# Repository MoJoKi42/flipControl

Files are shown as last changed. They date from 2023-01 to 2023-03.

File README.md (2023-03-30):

# flipControl
Full controller for **BROSE** and **LAWO FlipDot** panels based on STM32 µC. Controllable via RS232, RS485 or 3.3V Serial.
With the DIP switches you can decide between BROSE / LAWO and set more parameters without reprogramming.

<ins>Software/µC:</ins>
- **STM32F103C8Tx** / BluePill Dev-Board
- CubeMX and HAL Libs
- "compile_and_flash.sh" to complile and flash µC under Linux

<ins>Hardware/PCB:</ins>
- PCB + Circuit made with EAGLE 6.6.0
- Gerber Files are in "Gerber.zip"

Picture of the finished board with soldered RS323 interface:
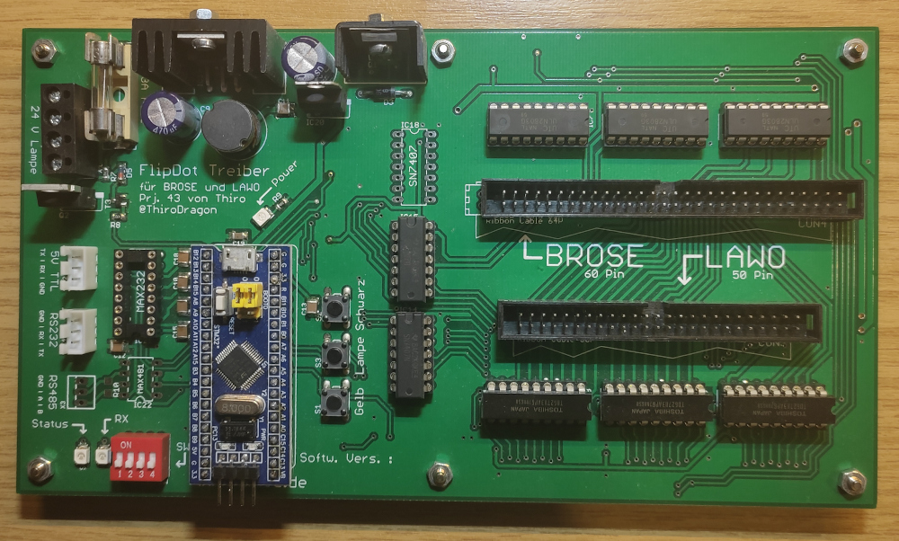
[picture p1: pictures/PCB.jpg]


Two different font types are possible (if you render the text with the MCU):
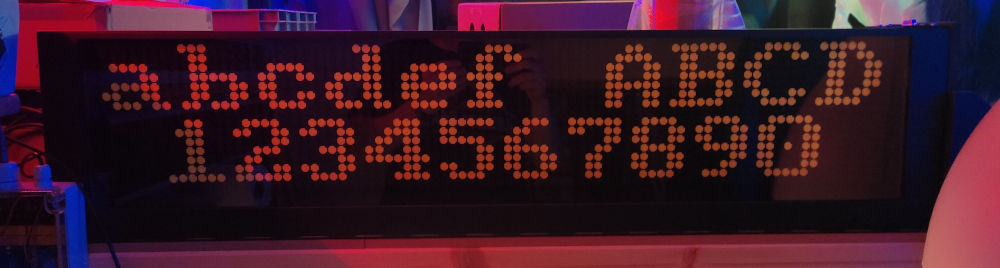
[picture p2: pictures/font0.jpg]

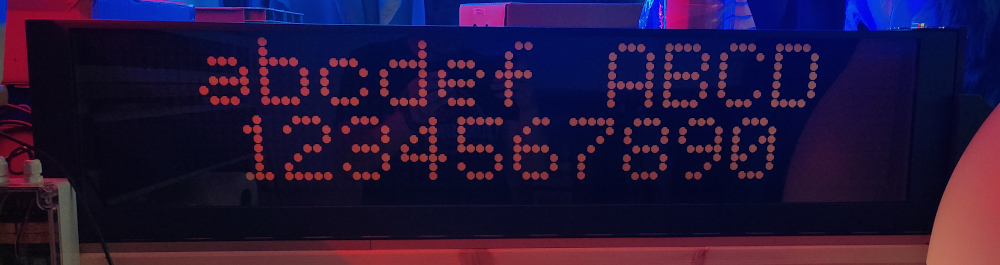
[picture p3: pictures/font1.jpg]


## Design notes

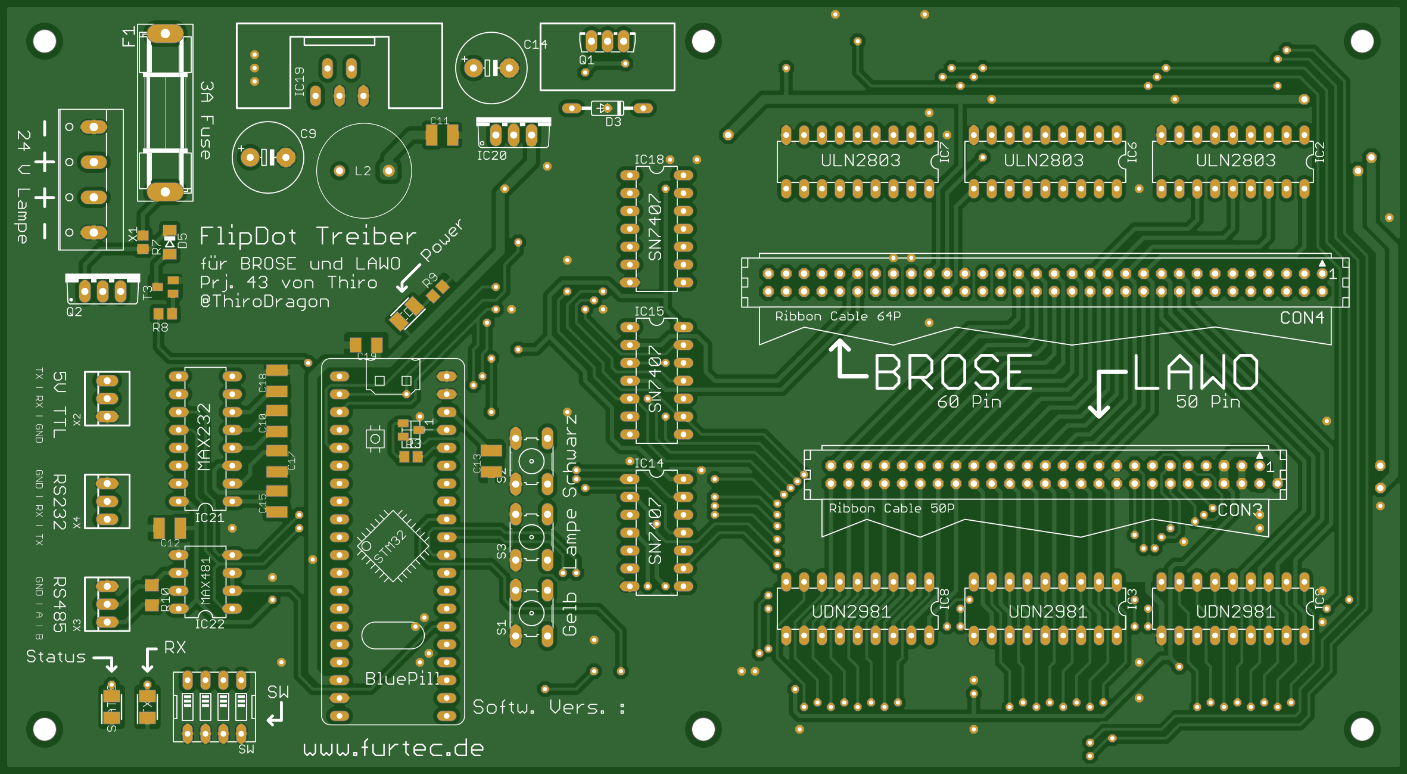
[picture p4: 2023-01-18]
pictures/Top.png

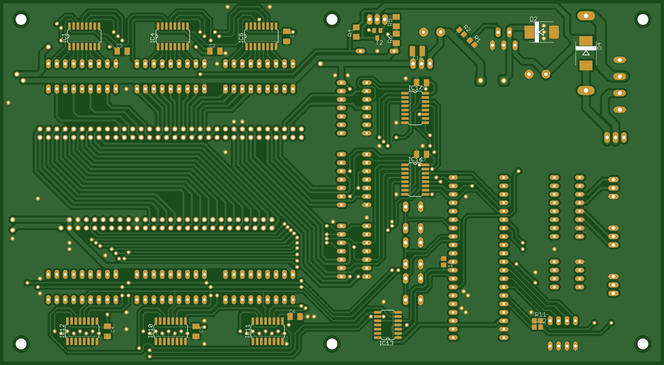
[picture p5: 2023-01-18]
pictures/Bottom.png

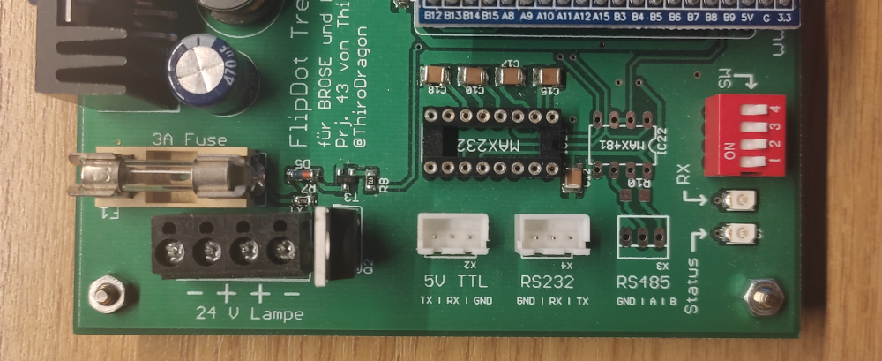
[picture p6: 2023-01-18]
pictures/connections.jpg

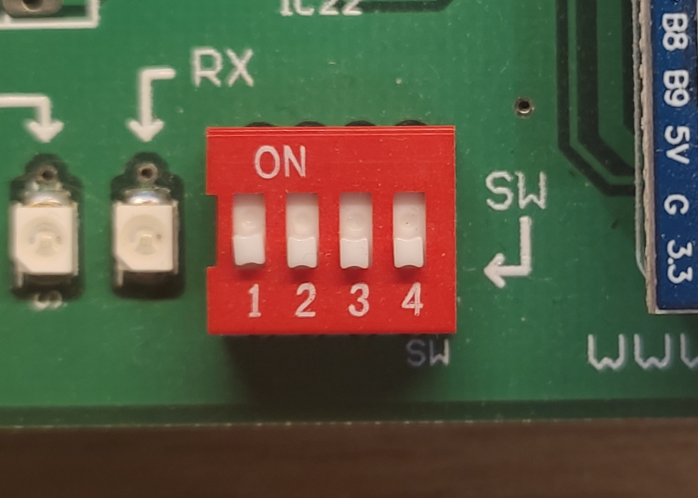
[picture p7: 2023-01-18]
pictures/switches.jpg

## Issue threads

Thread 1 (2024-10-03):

Textausgabe

MG020162, 2024-10-03:
Gibt es ein Beispiel was alles über die serielle Schnittstelle gesendet werden muss um ein Text auszugeben? Die Hardware funktioniert soweit, die Dots schalten beim betätigen der Gelb und Schwarz Taster. Danke für die Hilfe.

MoJoKi42, 2024-10-08:
[Doku.pdf](https://github.com/user-attachments/files/17298290/Doku.pdf)
[FlipControl V1.2 vorläufig.py.zip](https://github.com/user-attachments/files/17298307/FlipControl.V1.2.vorlaufig.py.zip)

Ich habe hier eine noch nicht fertige Doku inkl. zugehöriger Python Lib. Sollte aber eigentlich weitgehend funktionieren. Hoffe damit konnte ich dir helfen.

Closed 2024-10-11.

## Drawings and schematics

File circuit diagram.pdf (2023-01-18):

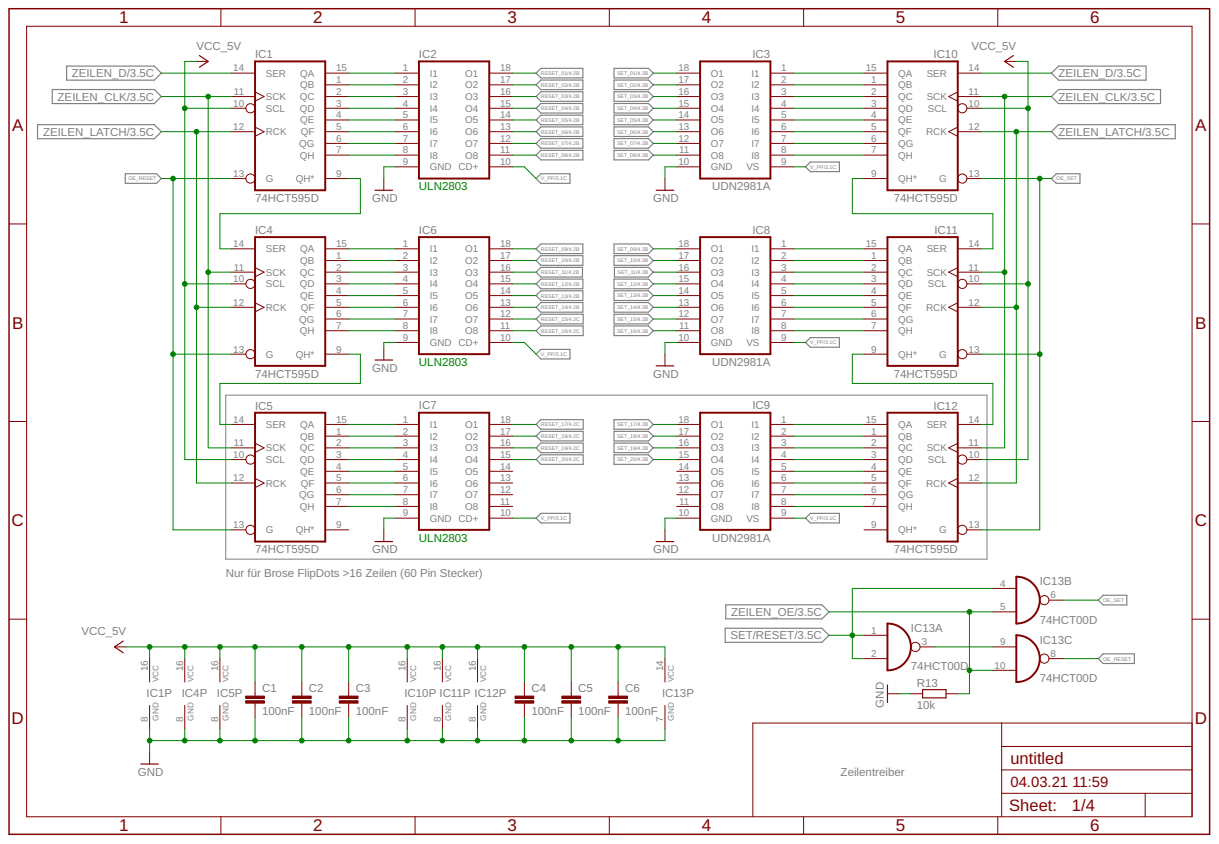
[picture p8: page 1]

74HCT595D
Nur für Brose FlipDots >16 Zeilen (60 Pin Stecker)

Zeilentreiber

Sheet: 1/4

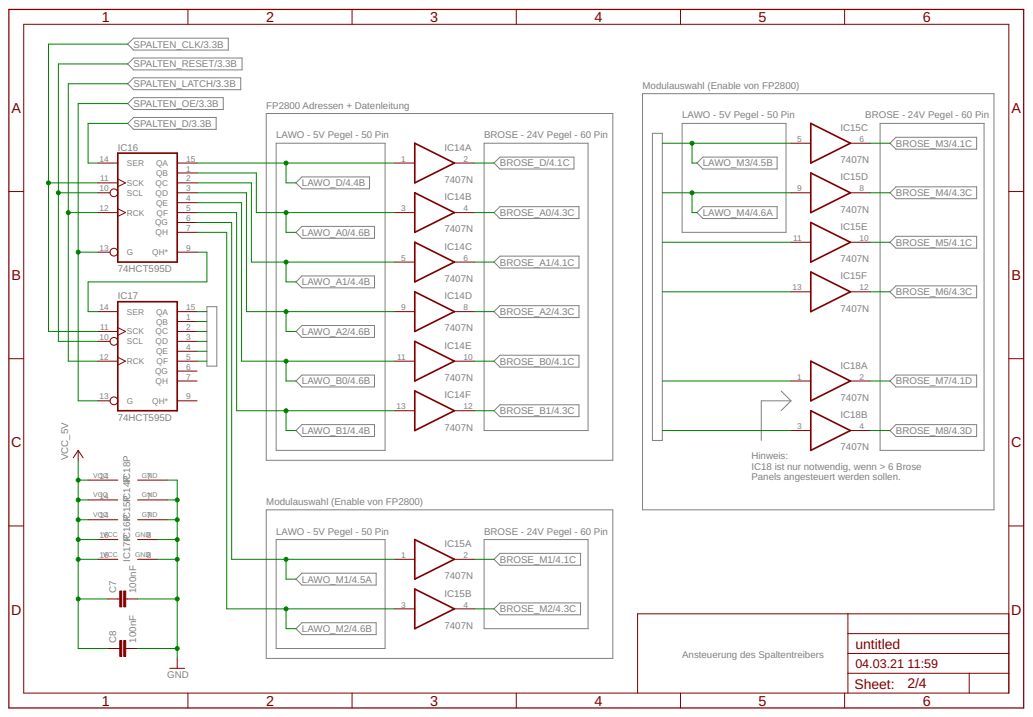
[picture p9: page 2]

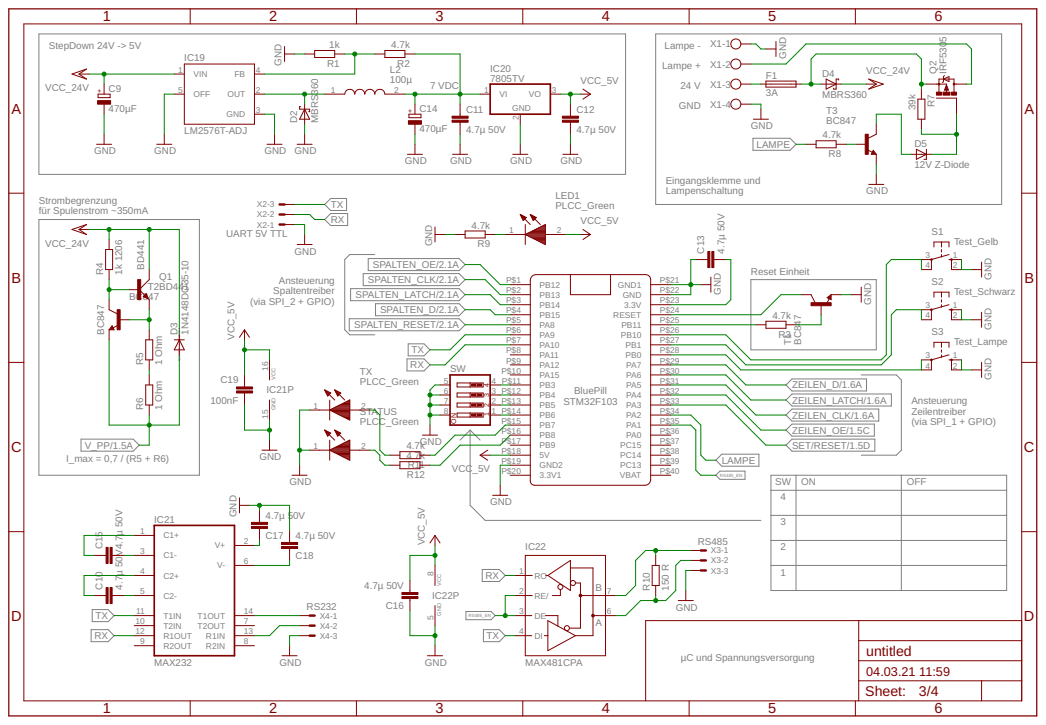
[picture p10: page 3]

SW | ON | OFF

µC und Spannungsversorgung

Sheet: 3/4

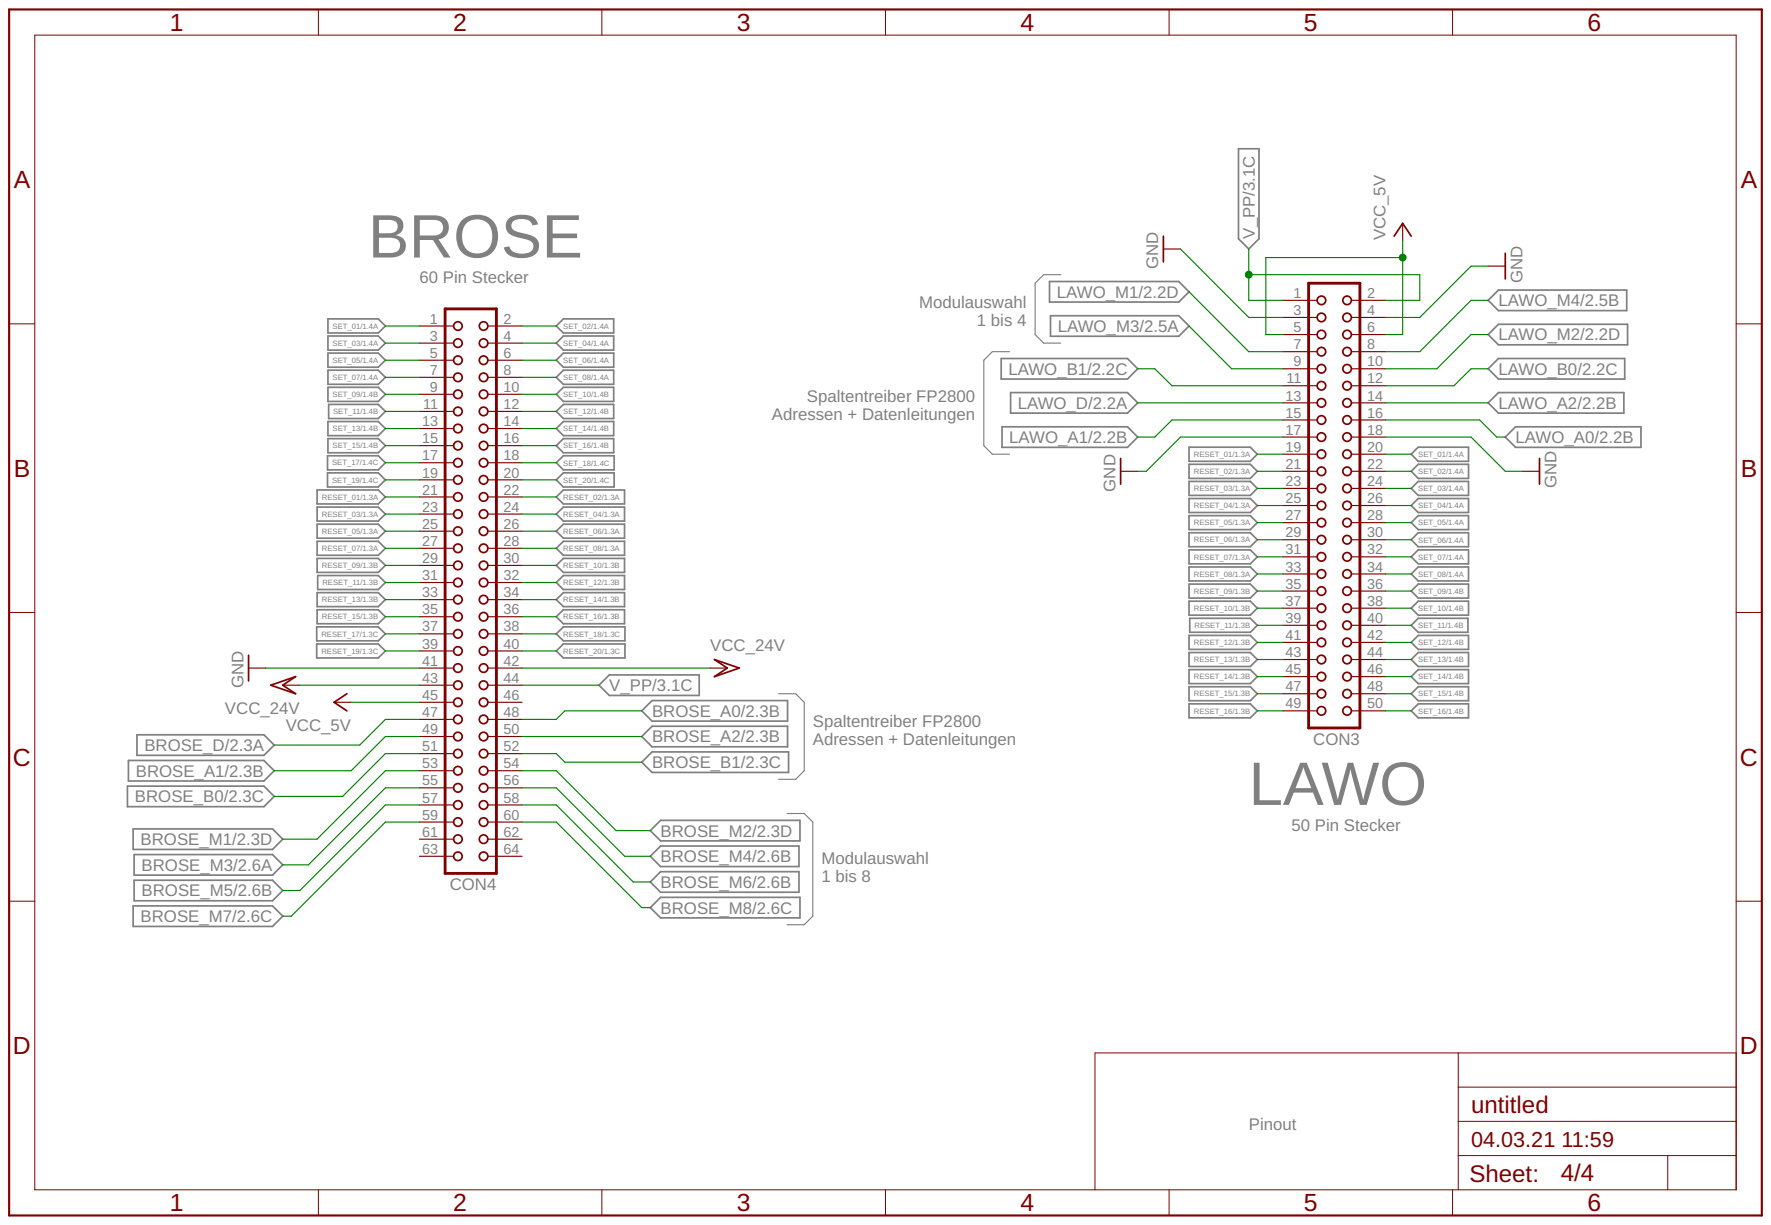
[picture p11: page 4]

Pinout

Sheet: 4/4

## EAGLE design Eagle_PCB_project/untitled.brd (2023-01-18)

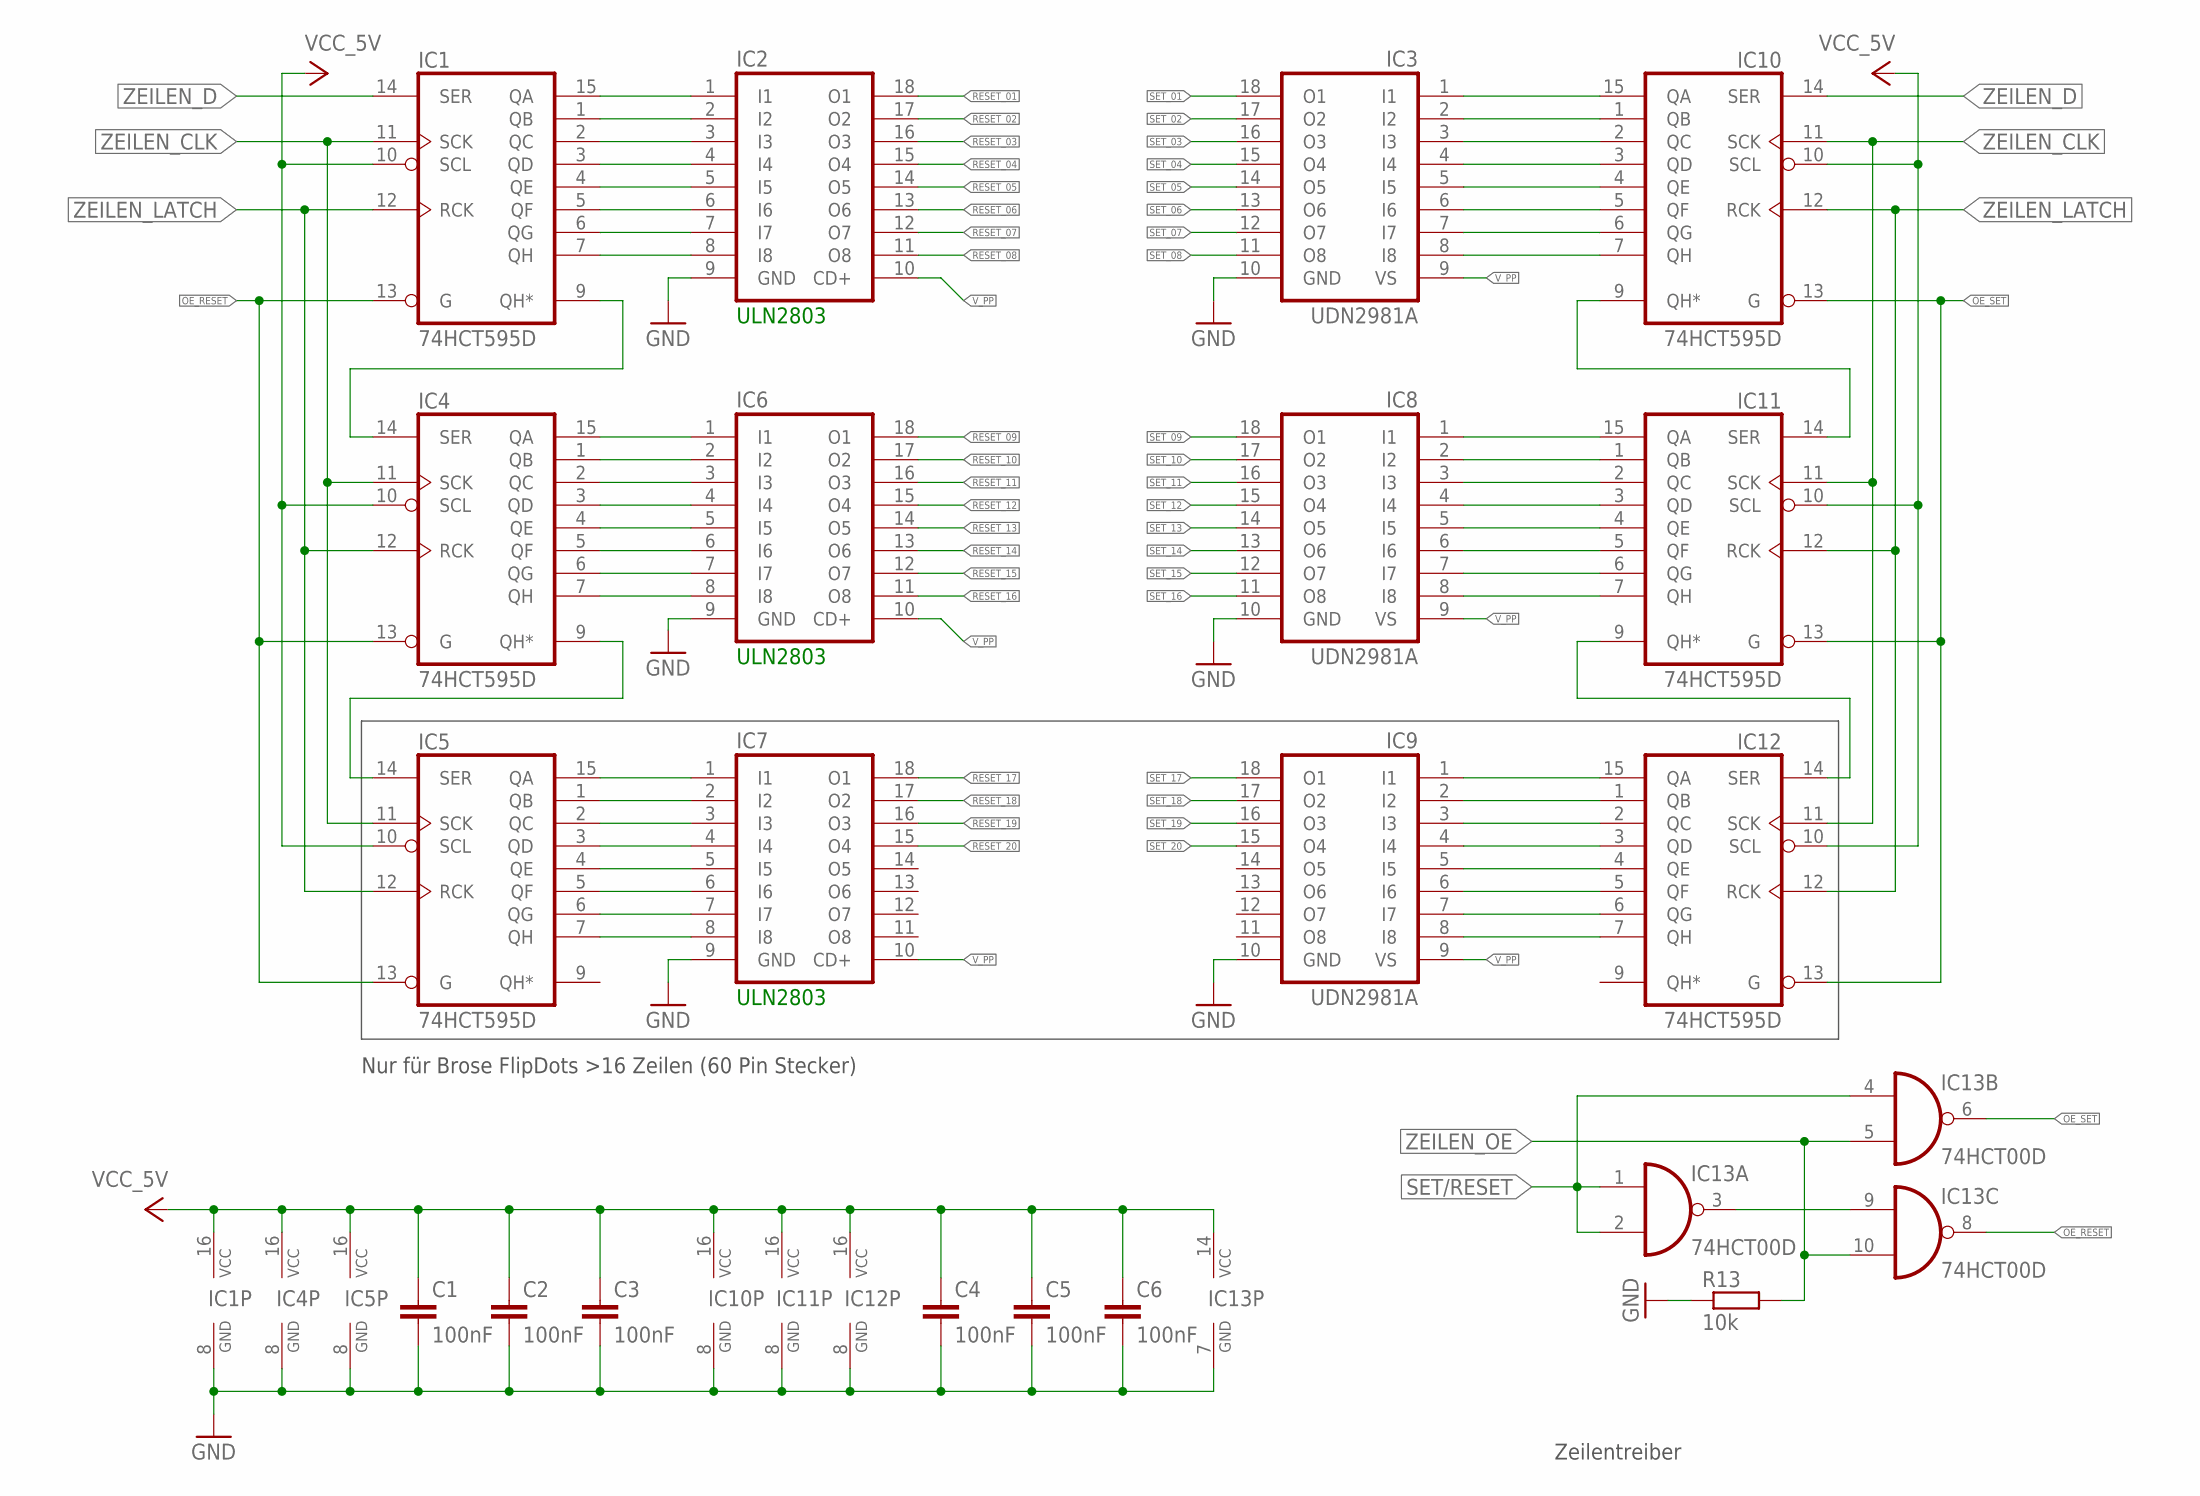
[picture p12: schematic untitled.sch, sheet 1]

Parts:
C1, C2, C3, C4, C5, C6: 100nF; C1206K
IC1, IC4, IC5, IC10, IC11, IC12: 74HCT595D; SO16
IC2, IC6, IC7: ULN2803A; DIL18
IC3, IC8, IC9: UDN2981A; DIL18
IC13: 74HCT00D; SO14
R13: 10k; R0805

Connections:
GND: C1.2, C2.2, C3.2, C4.2, C5.2, C6.2, IC1.8 (GND), IC2.9 (GND), IC3.10 (GND), IC4.8 (GND), IC5.8 (GND), IC6.9 (GND), IC7.9 (GND), IC8.10 (GND), IC9.10 (GND), IC10.8 (GND), IC11.8 (GND), IC12.8 (GND), IC13.7 (GND), R13.1; also elsewhere on the board
unnamed: IC1.9 (QH*), IC4.14 (SER)
unnamed: IC4.9 (QH*), IC5.14 (SER)
unnamed: IC4.15 (QA), IC6.1 (I1)
unnamed: IC4.1 (QB), IC6.2 (I2)
unnamed: IC4.2 (QC), IC6.3 (I3)
unnamed: IC4.3 (QD), IC6.4 (I4)
unnamed: IC4.4 (QE), IC6.5 (I5)
unnamed: IC4.5 (QF), IC6.6 (I6)
unnamed: IC4.6 (QG), IC6.7 (I7)
unnamed: IC4.7 (QH), IC6.8 (I8)
unnamed: IC1.15 (QA), IC2.1 (I1)
unnamed: IC1.1 (QB), IC2.2 (I2)
unnamed: IC1.2 (QC), IC2.3 (I3)
unnamed: IC1.3 (QD), IC2.4 (I4)
unnamed: IC1.4 (QE), IC2.5 (I5)
unnamed: IC1.5 (QF), IC2.6 (I6)
unnamed: IC1.6 (QG), IC2.7 (I7)
unnamed: IC1.7 (QH), IC2.8 (I8)
unnamed: IC5.15 (QA), IC7.1 (I1)
unnamed: IC5.1 (QB), IC7.2 (I2)
unnamed: IC5.2 (QC), IC7.3 (I3)
unnamed: IC5.3 (QD), IC7.4 (I4)
unnamed: IC5.4 (QE), IC7.5 (I5)
unnamed: IC5.5 (QF), IC7.6 (I6)
unnamed: IC5.6 (QG), IC7.7 (I7)
unnamed: IC5.7 (QH), IC7.8 (I8)
unnamed: IC3.2 (I2), IC10.1 (QB)
unnamed: IC3.3 (I3), IC10.2 (QC)
unnamed: IC3.4 (I4), IC10.3 (QD)
unnamed: IC3.5 (I5), IC10.4 (QE)
unnamed: IC3.6 (I6), IC10.5 (QF)
unnamed: IC3.7 (I7), IC10.6 (QG)
unnamed: IC3.8 (I8), IC10.7 (QH)
unnamed: IC3.1 (I1), IC10.15 (QA)
unnamed: IC8.2 (I2), IC11.1 (QB)
unnamed: IC8.3 (I3), IC11.2 (QC)
unnamed: IC8.4 (I4), IC11.3 (QD)
unnamed: IC8.5 (I5), IC11.4 (QE)
unnamed: IC8.6 (I6), IC11.5 (QF)
unnamed: IC8.7 (I7), IC11.6 (QG)
unnamed: IC8.8 (I8), IC11.7 (QH)
unnamed: IC8.1 (I1), IC11.15 (QA)
unnamed: IC9.2 (I2), IC12.1 (QB)
unnamed: IC9.3 (I3), IC12.2 (QC)
unnamed: IC9.4 (I4), IC12.3 (QD)
unnamed: IC9.5 (I5), IC12.4 (QE)
unnamed: IC9.6 (I6), IC12.5 (QF)
unnamed: IC9.7 (I7), IC12.6 (QG)
unnamed: IC9.8 (I8), IC12.7 (QH)
unnamed: IC9.1 (I1), IC12.15 (QA)
unnamed: IC10.9 (QH*), IC11.14 (SER)
unnamed: IC11.9 (QH*), IC12.14 (SER)
unnamed: IC13.3 (O), IC13.9 (I0)
OE_RESET: IC1.13 (G), IC4.13 (G), IC5.13 (G), IC13.8 (O)
OE_SET: IC10.13 (G), IC11.13 (G), IC12.13 (G), IC13.6 (O)
RESET_01: IC2.18 (O1); also elsewhere on the board
RESET_02: IC2.17 (O2); also elsewhere on the board
RESET_03: IC2.16 (O3); also elsewhere on the board
RESET_04: IC2.15 (O4); also elsewhere on the board
RESET_05: IC2.14 (O5); also elsewhere on the board
RESET_06: IC2.13 (O6); also elsewhere on the board
RESET_07: IC2.12 (O7); also elsewhere on the board
RESET_08: IC2.11 (O8); also elsewhere on the board
RESET_09: IC6.18 (O1); also elsewhere on the board
RESET_10: IC6.17 (O2); also elsewhere on the board
RESET_11: IC6.16 (O3); also elsewhere on the board
RESET_12: IC6.15 (O4); also elsewhere on the board
RESET_13: IC6.14 (O5); also elsewhere on the board
RESET_14: IC6.13 (O6); also elsewhere on the board
RESET_15: IC6.12 (O7); also elsewhere on the board
RESET_16: IC6.11 (O8); also elsewhere on the board
RESET_17: IC7.18 (O1); also elsewhere on the board
RESET_18: IC7.17 (O2); also elsewhere on the board
RESET_19: IC7.16 (O3); also elsewhere on the board
RESET_20: IC7.15 (O4); also elsewhere on the board
SET/RESET: IC13.1 (I0), IC13.2 (I1), IC13.4 (I0); also elsewhere on the board
SET_01: IC3.18 (O1); also elsewhere on the board
SET_02: IC3.17 (O2); also elsewhere on the board
SET_03: IC3.16 (O3); also elsewhere on the board
SET_04: IC3.15 (O4); also elsewhere on the board
SET_05: IC3.14 (O5); also elsewhere on the board
SET_06: IC3.13 (O6); also elsewhere on the board
SET_07: IC3.12 (O7); also elsewhere on the board
SET_08: IC3.11 (O8); also elsewhere on the board
SET_09: IC8.18 (O1); also elsewhere on the board
SET_10: IC8.17 (O2); also elsewhere on the board
SET_11: IC8.16 (O3); also elsewhere on the board
SET_12: IC8.15 (O4); also elsewhere on the board
SET_13: IC8.14 (O5); also elsewhere on the board
SET_14: IC8.13 (O6); also elsewhere on the board
SET_15: IC8.12 (O7); also elsewhere on the board
SET_16: IC8.11 (O8); also elsewhere on the board
SET_17: IC9.18 (O1); also elsewhere on the board
SET_18: IC9.17 (O2); also elsewhere on the board
SET_19: IC9.16 (O3); also elsewhere on the board
SET_20: IC9.15 (O4); also elsewhere on the board
VCC: C1.1, C2.1, C3.1, C4.1, C5.1, C6.1, IC1.10 (SCL), IC1.16 (VCC), IC4.10 (SCL), IC4.16 (VCC), IC5.10 (SCL), IC5.16 (VCC), IC10.10 (SCL), IC10.16 (VCC), IC11.10 (SCL), IC11.16 (VCC), IC12.10 (SCL), IC12.16 (VCC), IC13.14 (VCC); also elsewhere on the board
V_PP: IC2.10 (CD+), IC3.9 (VS), IC6.10 (CD+), IC7.10 (CD+), IC8.9 (VS), IC9.9 (VS); also elsewhere on the board
ZEILEN_CLK: IC1.11 (SCK), IC4.11 (SCK), IC5.11 (SCK), IC10.11 (SCK), IC11.11 (SCK), IC12.11 (SCK); also elsewhere on the board
ZEILEN_D: IC1.14 (SER), IC10.14 (SER); also elsewhere on the board
ZEILEN_LATCH: IC1.12 (RCK), IC4.12 (RCK), IC5.12 (RCK), IC10.12 (RCK), IC11.12 (RCK), IC12.12 (RCK); also elsewhere on the board
ZEILEN_OE: IC13.5 (I1), IC13.10 (I1), R13.2; also elsewhere on the board

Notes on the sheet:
ULN2803
Nur für Brose FlipDots >16 Zeilen (60 Pin Stecker)
Zeilentreiber

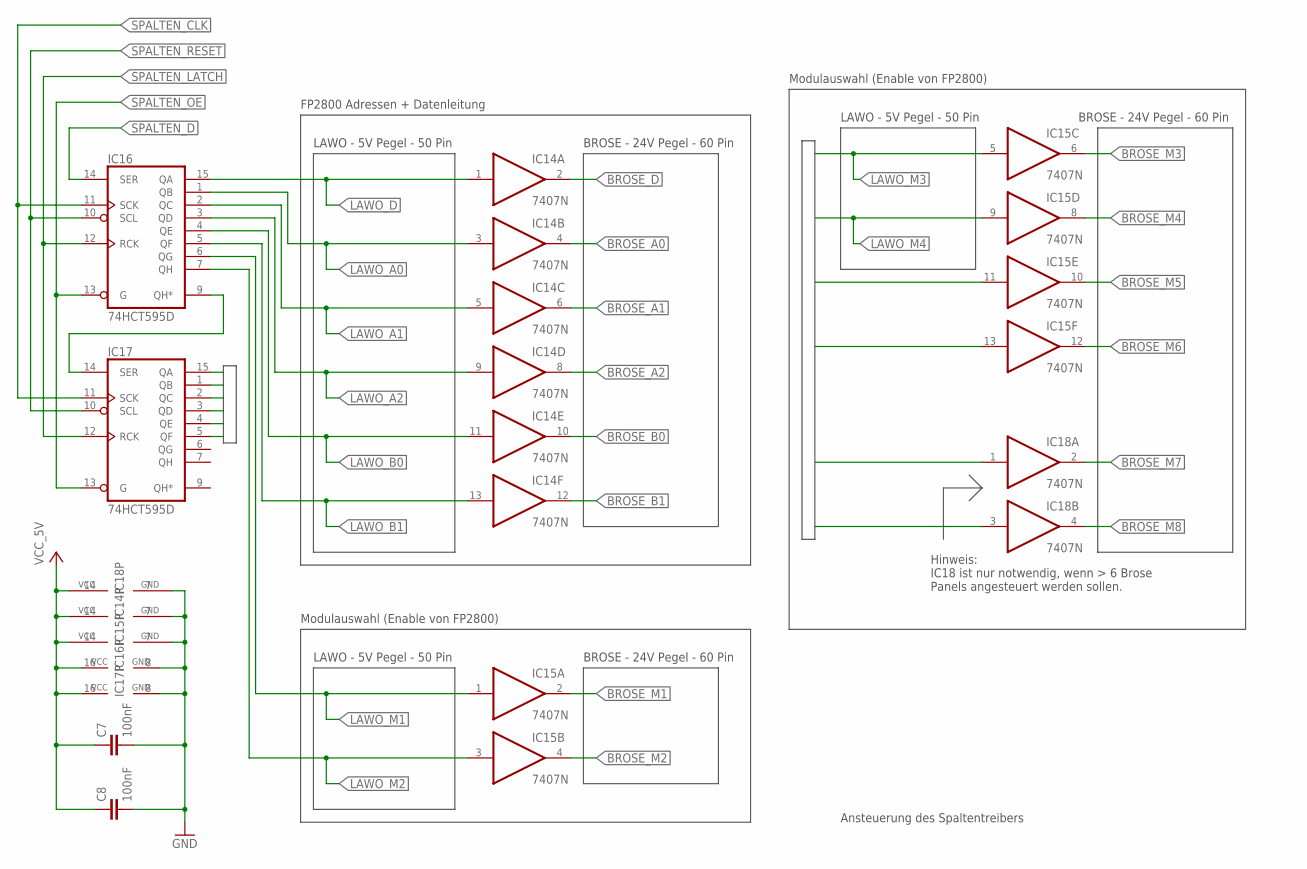
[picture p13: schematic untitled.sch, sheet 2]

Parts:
C7, C8: 100nF; C1206K
IC14, IC15, IC18: 7407N; DIL14
IC16, IC17: 74HCT595D; SO16

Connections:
BROSE_A0: IC14.4 (O); also elsewhere on the board
BROSE_A1: IC14.6 (O); also elsewhere on the board
BROSE_A2: IC14.8 (O); also elsewhere on the board
BROSE_B0: IC14.10 (O); also elsewhere on the board
BROSE_B1: IC14.12 (O); also elsewhere on the board
BROSE_D: IC14.2 (O); also elsewhere on the board
BROSE_M1: IC15.2 (O); also elsewhere on the board
BROSE_M2: IC15.4 (O); also elsewhere on the board
BROSE_M3: IC15.6 (O); also elsewhere on the board
BROSE_M4: IC15.8 (O); also elsewhere on the board
BROSE_M5: IC15.10 (O); also elsewhere on the board
BROSE_M6: IC15.12 (O); also elsewhere on the board
BROSE_M7: IC18.2 (O); also elsewhere on the board
BROSE_M8: IC18.4 (O); also elsewhere on the board
GND: C7.2, C8.2, IC14.7 (GND), IC15.7 (GND), IC16.8 (GND), IC17.8 (GND), IC18.7 (GND); also elsewhere on the board
LAWO_A0: IC14.3 (I), IC16.1 (QB); also elsewhere on the board
LAWO_A1: IC14.5 (I), IC16.2 (QC); also elsewhere on the board
LAWO_A2: IC14.9 (I), IC16.3 (QD); also elsewhere on the board
LAWO_B0: IC14.11 (I), IC16.4 (QE); also elsewhere on the board
LAWO_B1: IC14.13 (I), IC16.5 (QF); also elsewhere on the board
LAWO_D: IC14.1 (I), IC16.15 (QA); also elsewhere on the board
LAWO_M1: IC15.1 (I), IC16.6 (QG); also elsewhere on the board
LAWO_M2: IC15.3 (I), IC16.7 (QH); also elsewhere on the board
LAWO_M3: IC15.5 (I), IC17.15 (QA); also elsewhere on the board
LAWO_M4: IC15.9 (I), IC17.1 (QB); also elsewhere on the board
LAWO_M5: IC15.11 (I), IC17.2 (QC)
LAWO_M6: IC15.13 (I), IC17.3 (QD)
LAWO_M7: IC17.4 (QE), IC18.1 (I)
LAWO_M8: IC17.5 (QF), IC18.3 (I)
unnamed: IC16.9 (QH*), IC17.14 (SER)
SPALTEN_CLK: IC16.11 (SCK), IC17.11 (SCK); also elsewhere on the board
SPALTEN_D: IC16.14 (SER); also elsewhere on the board
SPALTEN_LATCH: IC16.12 (RCK), IC17.12 (RCK); also elsewhere on the board
SPALTEN_OE: IC16.13 (G), IC17.13 (G); also elsewhere on the board
SPALTEN_RESET: IC16.10 (SCL), IC17.10 (SCL); also elsewhere on the board
VCC: C7.1, C8.1, IC14.14 (VCC), IC15.14 (VCC), IC16.16 (VCC), IC17.16 (VCC), IC18.14 (VCC); also elsewhere on the board

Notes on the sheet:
LAWO - 5V Pegel - 50 Pin
BROSE - 24V Pegel - 60 Pin
FP2800 Adressen + Datenleitung
Modulauswahl (Enable von FP2800)
Hinweis: IC18 ist nur notwendig, wenn > 6 Brose Panels angesteuert werden sollen.
Ansteuerung des Spaltentreibers

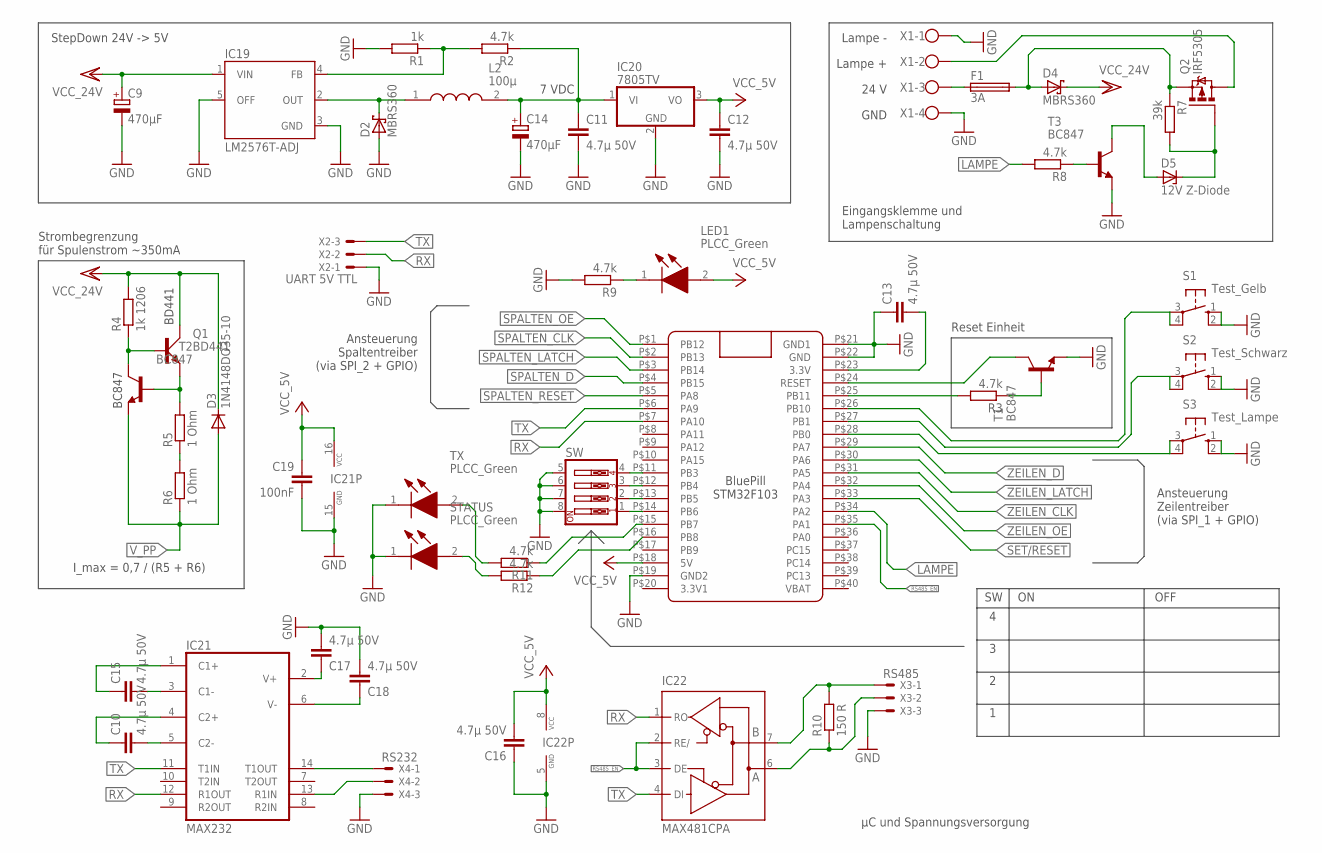
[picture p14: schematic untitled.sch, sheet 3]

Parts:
C9, C14: 470µF; E5-10,5
C10, C11, C12, C13, C15, C16, C17, C18: 4.7µ 50V; C1210K
C19: 100nF; C1206K
D2, D4: MBRS360; SMC
D3: 1N4148DO35-10; DO35-10
D5: 12V Z-Diode; SOD80C
F1: 3A; SH22,5
IC19: LM2576T-ADJ; TO220-5
IC20: 7805TV; TO220V
IC21: MAX232; DIL16
IC22: MAX481CPA; DIL08
L2: 100µ; 09HCP121M50
LED1: PLCC_Green; LEDM3528X190N
Q1: BD441; TO126AV
Q2: IRF5305; TO220BV
R1: 1k; R0805
R2, R3, R8, R9, R11, R12: 4.7k; R0805
R4: 1k 1206; R1206
R5, R6: 1 Ohm; M1206
R7: 39k; R0805
R10: 150 R; R1206
S1: Test_Gelb; B3F-10XX
S2: Test_Schwarz; B3F-10XX
S3: Test_Lampe; B3F-10XX
STATUS: PLCC_Green; LEDM3528X190N
SW: SW_DIP-4; EDG-04
T1, T2, T3: BC847; SOT23
TX: PLCC_Green; LEDM3528X190N
U$1: BLUE_PILL
X1: W237-4
X2: UART 5V TTL; 22-23-2031
X3: RS485; 22-23-2031
X4: RS232; 22-23-2031

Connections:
GND: C9.-, C11.2, C12.2, C13.1, C14.-, C16.1, C17.2, C18.2, C19.2, D2.A, IC19.3 (GND), IC19.5 (OFF), IC20.2 (GND), IC21.15 (GND), IC22.5 (GND), R1.2, R9.2, S1.1 (S), S1.2 (S1), S2.1 (S), S2.2 (S1), S3.1 (S), S3.2 (S1), STATUS.1 (K), SW.5, SW.6, SW.7, SW.8, T1.2 (E), T3.2 (E), TX.1 (K), U$1.P$19 (GND2), U$1.P$21 (GND1), U$1.P$22 (GND), X1.1, X1.4, X2.1, X3.3, X4.3; also elsewhere on the board
LAMPE: R8.2, U$1.P$34 (PA2)
unnamed: R5.1, R6.2
unnamed: D5.A, T3.3 (C)
unnamed: F1.1, X1.3
unnamed: D5.C, Q2.G, R7.2
unnamed: D4.A, F1.2, Q2.S, R7.1
unnamed: R8.1, T3.1 (B)
unnamed: SW.1, U$1.P$14 (PB6)
unnamed: SW.2, U$1.P$13 (PB5)
unnamed: SW.3, U$1.P$12 (PB4)
unnamed: SW.4, U$1.P$11 (PB3)
unnamed: LED1.1 (K), R9.1
unnamed: IC22.6 (A), R10.1, X3.2
unnamed: IC22.7 (B), R10.2, X3.1
unnamed: C10.2, IC21.5 (C2-)
unnamed: C10.1, IC21.4 (C2+)
unnamed: IC21.14 (T1OUT), X4.1
unnamed: C15.2, IC21.3 (C1-)
unnamed: C15.1, IC21.1 (C1+)
unnamed: IC21.13 (R1IN), X4.2
unnamed: C17.1, IC21.2 (V+)
unnamed: C18.1, IC21.6 (V-)
unnamed: Q2.D, X1.2
unnamed: R11.1, U$1.P$15 (PB7)
unnamed: R12.1, U$1.P$16 (PB8)
unnamed: R12.2, STATUS.2 (A)
unnamed: R11.2, TX.2 (A)
unnamed: C11.1, C14.+, IC20.1 (VI), L2.2, R2.1
unnamed: D2.C, IC19.2 (OUT), L2.1
unnamed: IC19.4 (FB), R1.1, R2.2
unnamed: R3.1, T1.1 (B)
unnamed: T1.3 (C), U$1.P$24 (RESET)
unnamed: R3.2, U$1.P$25 (PB11)
unnamed: Q1.B, R4.1, T2.3 (C)
unnamed: Q1.E, R5.2, T2.1 (B)
unnamed: S2.3, S2.4 (P1), U$1.P$27 (PB1)
unnamed: S1.3, S1.4 (P1), U$1.P$26 (PB10)
unnamed: S3.3, S3.4 (P1), U$1.P$28 (PB0)
unnamed: C13.2, U$1.P$23 (3.3V)
RS485_EN: IC22.2 (RE/), IC22.3 (DE), U$1.P$35 (PA1)
RX: IC21.12 (R1OUT), IC22.1 (RO), U$1.P$7 (PA10), X2.2
SET/RESET: U$1.P$33 (PA3); also elsewhere on the board
SPALTEN_CLK: U$1.P$2 (PB13); also elsewhere on the board
SPALTEN_D: U$1.P$4 (PB15); also elsewhere on the board
SPALTEN_LATCH: U$1.P$3 (PB14); also elsewhere on the board
SPALTEN_OE: U$1.P$1 (PB12); also elsewhere on the board
SPALTEN_RESET: U$1.P$5 (PA8); also elsewhere on the board
TX: IC21.11 (T1IN), IC22.4 (DI), U$1.P$6 (PA9), X2.3
VCC: C12.1, C16.2, C19.1, IC20.3 (VO), IC21.16 (VCC), IC22.8 (VCC), LED1.2 (A), U$1.P$18 (5V); also elsewhere on the board
VCC/2: C9.+, D3.C, D4.C, IC19.1 (VIN), Q1.C, R4.2; also elsewhere on the board
V_PP: D3.A, R6.1, T2.2 (E); also elsewhere on the board
ZEILEN_CLK: U$1.P$31 (PA5); also elsewhere on the board
ZEILEN_D: U$1.P$29 (PA7); also elsewhere on the board
ZEILEN_LATCH: U$1.P$30 (PA6); also elsewhere on the board
ZEILEN_OE: U$1.P$32 (PA4); also elsewhere on the board

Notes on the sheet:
7 VDC
Reset Einheit
BC847
BD441
Strombegrenzung für Spulenstrom ~350mA
µC und Spannungsversorgung
I_max = 0,7 / (R5 + R6)
StepDown 24V -> 5V
GND
24 V
Lampe +
Lampe -
Eingangsklemme und Lampenschaltung
Ansteuerung Zeilentreiber (via SPI_1 + GPIO)
Ansteuerung Spaltentreiber (via SPI_2 + GPIO)
OFF
BluePill STM32F103

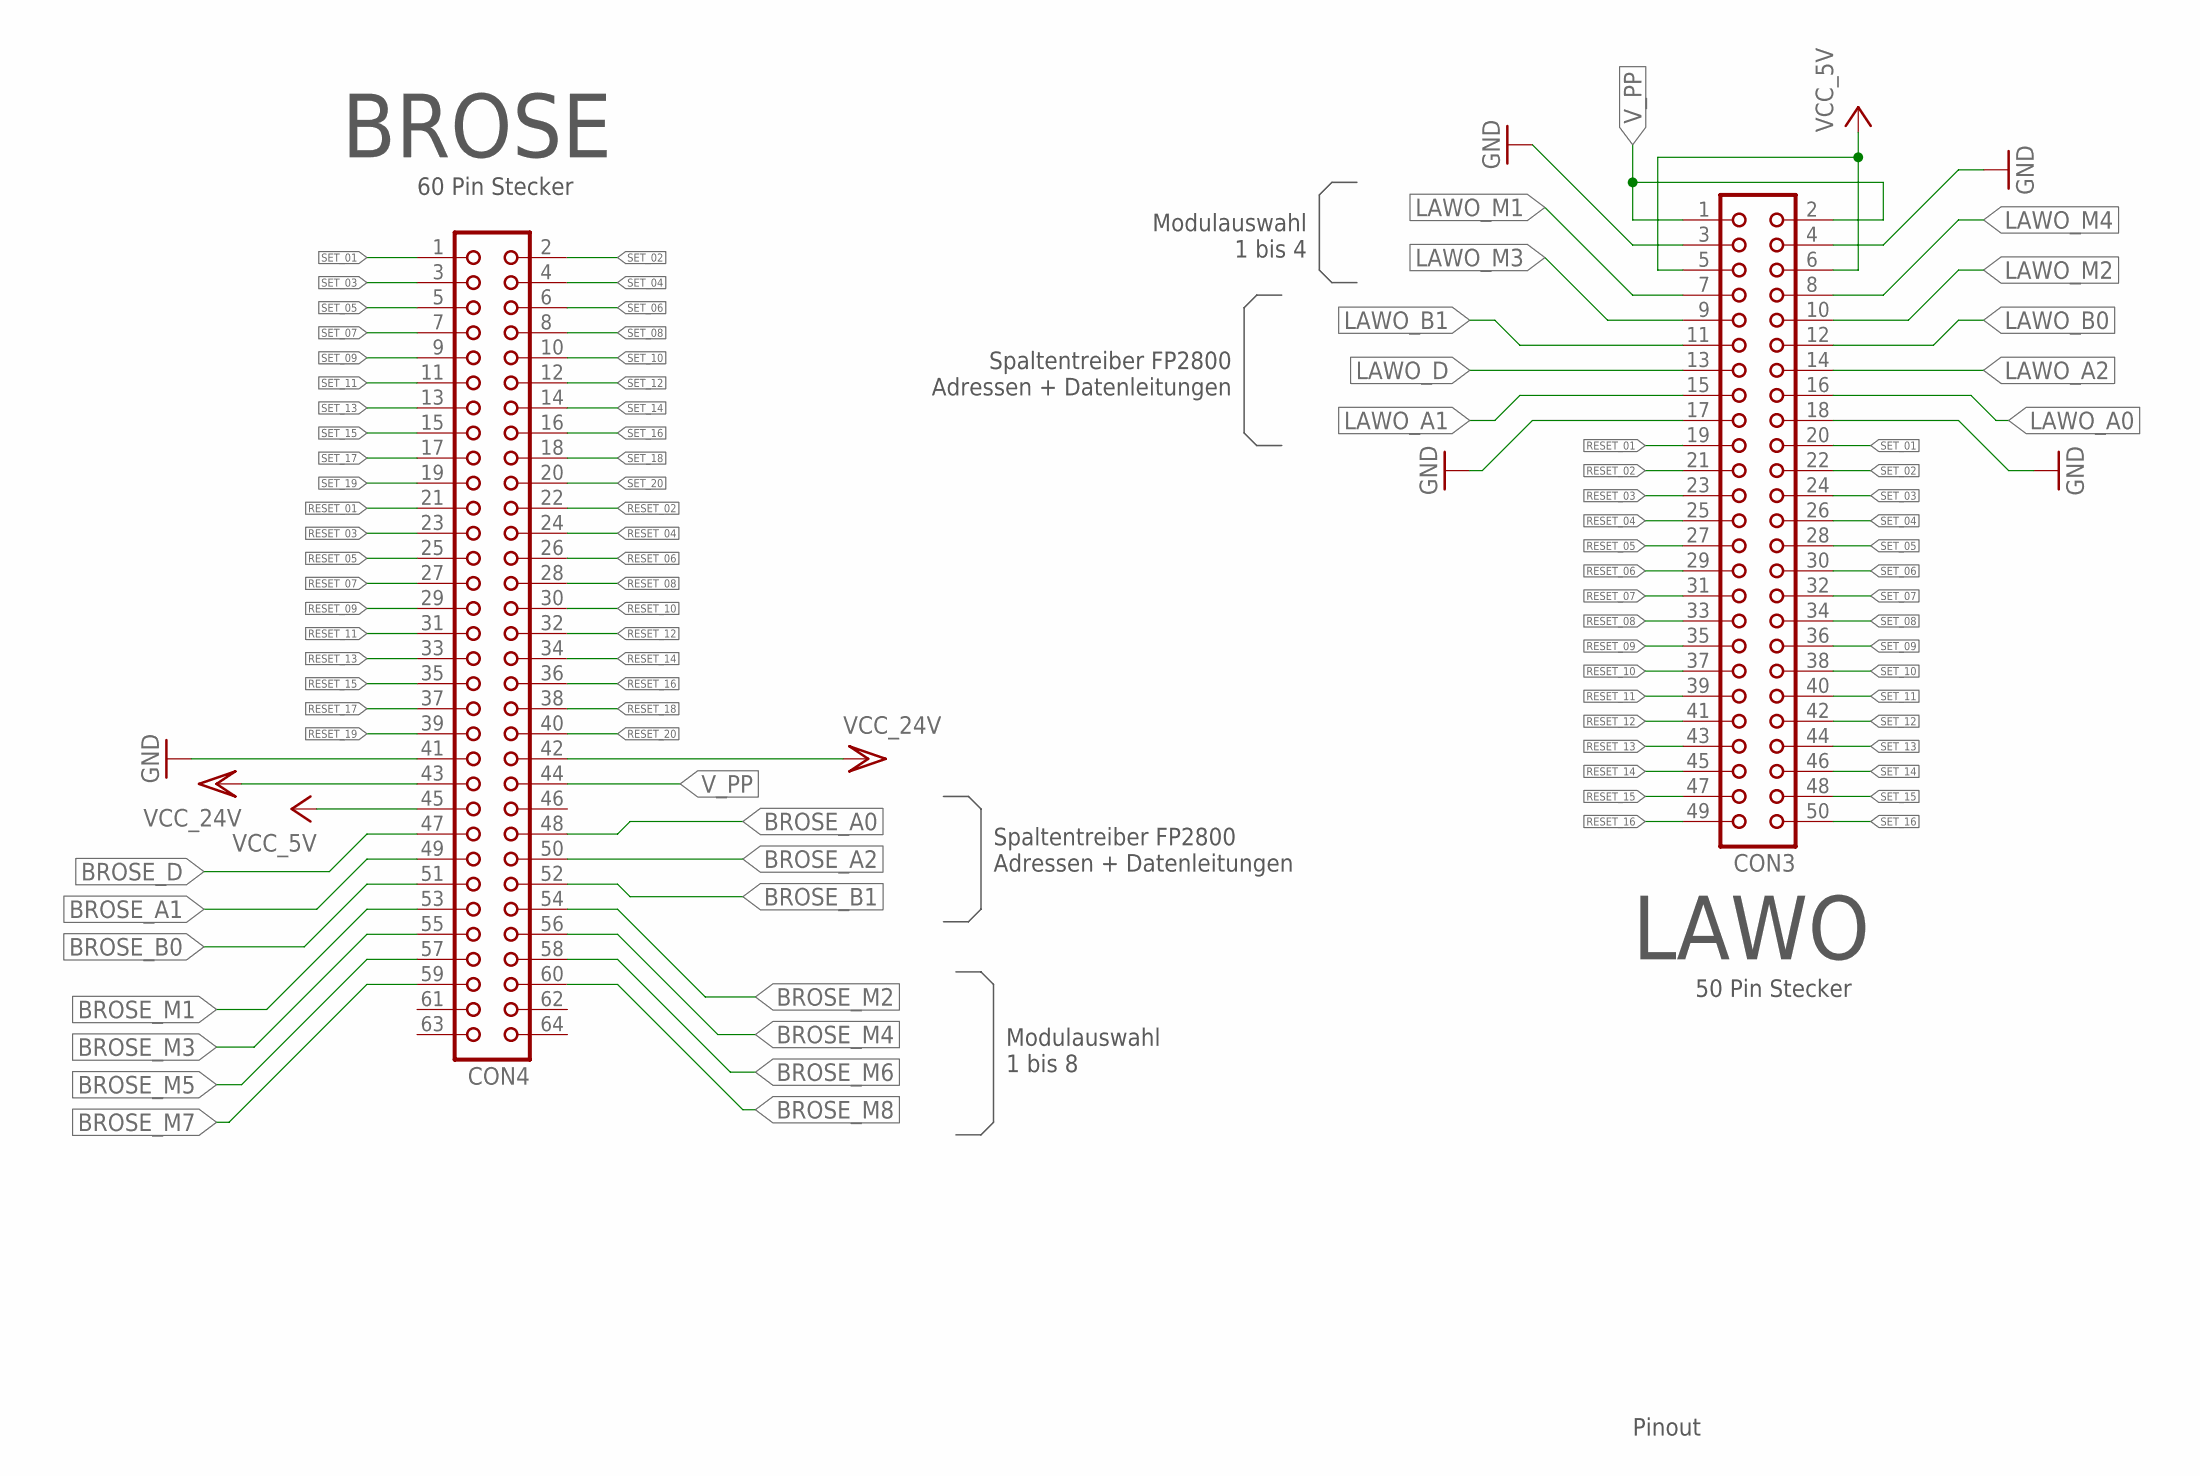
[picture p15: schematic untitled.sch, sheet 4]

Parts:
CON3: CON50
CON4: CON64

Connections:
BROSE_A0: CON4.48; also elsewhere on the board
BROSE_A1: CON4.49; also elsewhere on the board
BROSE_A2: CON4.50; also elsewhere on the board
BROSE_B0: CON4.51; also elsewhere on the board
BROSE_B1: CON4.52; also elsewhere on the board
BROSE_D: CON4.47; also elsewhere on the board
BROSE_M1: CON4.53; also elsewhere on the board
BROSE_M2: CON4.54; also elsewhere on the board
BROSE_M3: CON4.55; also elsewhere on the board
BROSE_M4: CON4.56; also elsewhere on the board
BROSE_M5: CON4.57; also elsewhere on the board
BROSE_M6: CON4.58; also elsewhere on the board
BROSE_M7: CON4.59; also elsewhere on the board
BROSE_M8: CON4.60; also elsewhere on the board
GND: CON3.3, CON3.4, CON3.17, CON3.18, CON4.41; also elsewhere on the board
LAWO_A0: CON3.16; also elsewhere on the board
LAWO_A1: CON3.15; also elsewhere on the board
LAWO_A2: CON3.14; also elsewhere on the board
LAWO_B0: CON3.12; also elsewhere on the board
LAWO_B1: CON3.11; also elsewhere on the board
LAWO_D: CON3.13; also elsewhere on the board
LAWO_M1: CON3.7; also elsewhere on the board
LAWO_M2: CON3.10; also elsewhere on the board
LAWO_M3: CON3.9; also elsewhere on the board
LAWO_M4: CON3.8; also elsewhere on the board
RESET_01: CON3.19, CON4.21; also elsewhere on the board
RESET_02: CON3.21, CON4.22; also elsewhere on the board
RESET_03: CON3.23, CON4.23; also elsewhere on the board
RESET_04: CON3.25, CON4.24; also elsewhere on the board
RESET_05: CON3.27, CON4.25; also elsewhere on the board
RESET_06: CON3.29, CON4.26; also elsewhere on the board
RESET_07: CON3.31, CON4.27; also elsewhere on the board
RESET_08: CON3.33, CON4.28; also elsewhere on the board
RESET_09: CON3.35, CON4.29; also elsewhere on the board
RESET_10: CON3.37, CON4.30; also elsewhere on the board
RESET_11: CON3.39, CON4.31; also elsewhere on the board
RESET_12: CON3.41, CON4.32; also elsewhere on the board
RESET_13: CON3.43, CON4.33; also elsewhere on the board
RESET_14: CON3.45, CON4.34; also elsewhere on the board
RESET_15: CON3.47, CON4.35; also elsewhere on the board
RESET_16: CON3.49, CON4.36; also elsewhere on the board
RESET_17: CON4.37; also elsewhere on the board
RESET_18: CON4.38; also elsewhere on the board
RESET_19: CON4.39; also elsewhere on the board
RESET_20: CON4.40; also elsewhere on the board
SET_01: CON3.20, CON4.1; also elsewhere on the board
SET_02: CON3.22, CON4.2; also elsewhere on the board
SET_03: CON3.24, CON4.3; also elsewhere on the board
SET_04: CON3.26, CON4.4; also elsewhere on the board
SET_05: CON3.28, CON4.5; also elsewhere on the board
SET_06: CON3.30, CON4.6; also elsewhere on the board
SET_07: CON3.32, CON4.7; also elsewhere on the board
SET_08: CON3.34, CON4.8; also elsewhere on the board
SET_09: CON3.36, CON4.9; also elsewhere on the board
SET_10: CON3.38, CON4.10; also elsewhere on the board
SET_11: CON3.40, CON4.11; also elsewhere on the board
SET_12: CON3.42, CON4.12; also elsewhere on the board
SET_13: CON3.44, CON4.13; also elsewhere on the board
SET_14: CON3.46, CON4.14; also elsewhere on the board
SET_15: CON3.48, CON4.15; also elsewhere on the board
SET_16: CON3.50, CON4.16; also elsewhere on the board
SET_17: CON4.17; also elsewhere on the board
SET_18: CON4.18; also elsewhere on the board
SET_19: CON4.19; also elsewhere on the board
SET_20: CON4.20; also elsewhere on the board
VCC: CON3.5, CON3.6, CON4.45; also elsewhere on the board
VCC/2: CON4.42, CON4.43; also elsewhere on the board
V_PP: CON3.1, CON3.2, CON4.44; also elsewhere on the board

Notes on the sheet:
Spaltentreiber FP2800 Adressen + Datenleitungen
Modulauswahl 1 bis 8
Modulauswahl 1 bis 4
Pinout
BROSE
LAWO
60 Pin Stecker
50 Pin Stecker

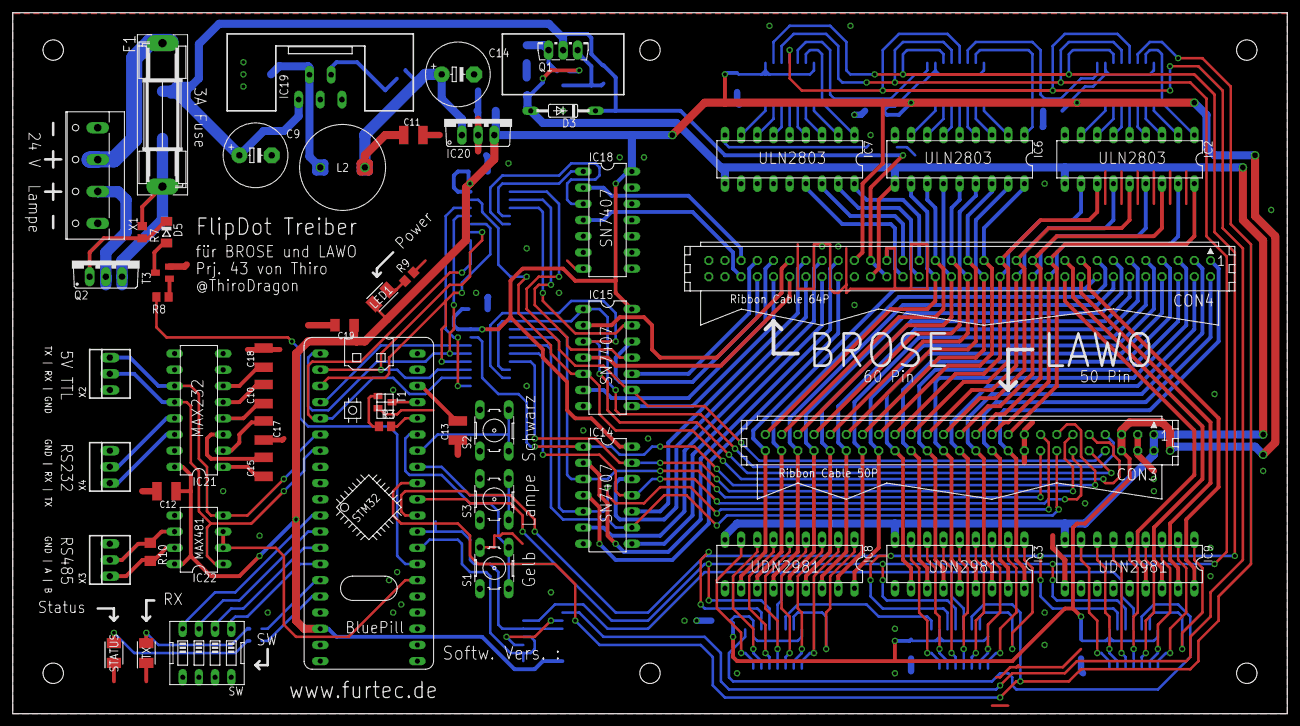
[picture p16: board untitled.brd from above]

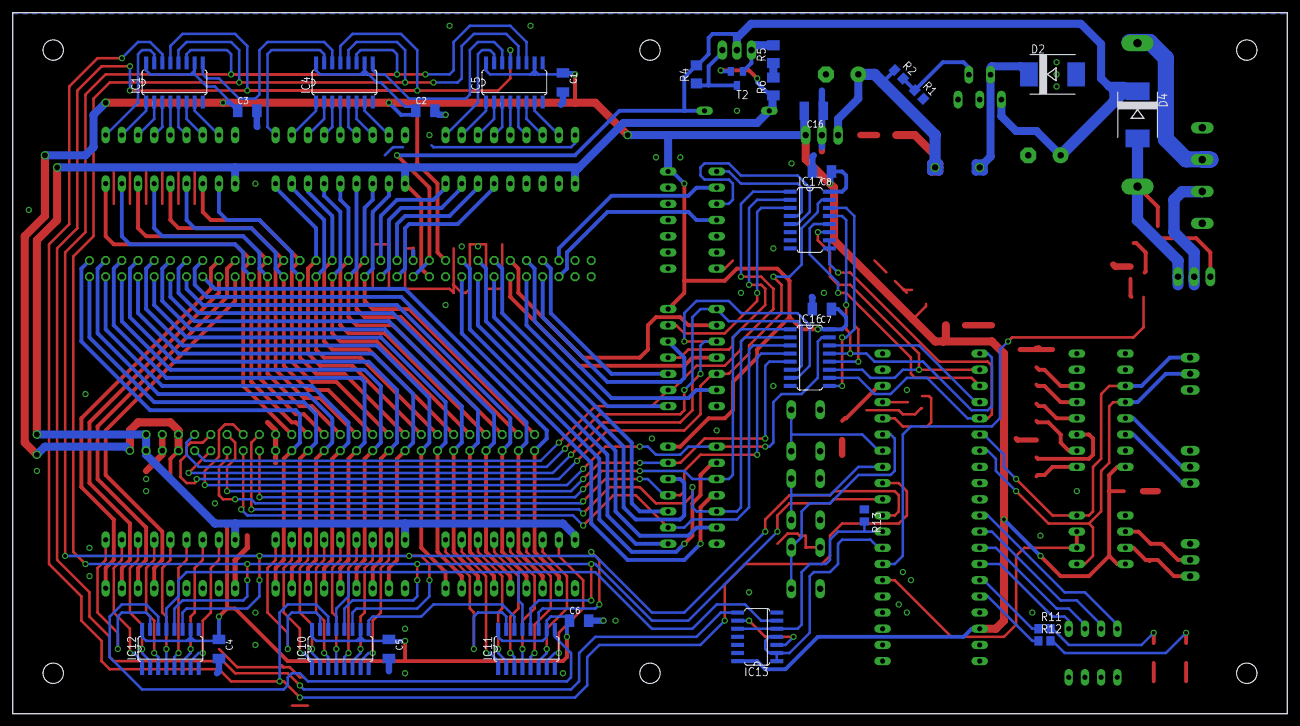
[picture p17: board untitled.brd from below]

Board: 2 copper layers, 200.0 x 110.0 mm, 79 parts (29 on the bottom side), 180 nets.

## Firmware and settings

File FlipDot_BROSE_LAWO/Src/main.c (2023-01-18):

/**
  ******************************************************************************
  * @file           : main.c
  * @brief          : Main program body
  ******************************************************************************
  ** This notice applies to any and all portions of this file
  * that are not between comment pairs USER CODE BEGIN and
  * USER CODE END. Other portions of this file, whether
  * inserted by the user or by software development tools
  * are owned by their respective copyright owners.
  *
  * COPYRIGHT(c) 2022 STMicroelectronics
  *
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
  ******************************************************************************
  */
/* Includes ------------------------------------------------------------------*/
#include "main.h"
#include "stm32f1xx_hal.h"
#include "spi.h"
#include "tim.h"
#include "usart.h"
#include "gpio.h"

/* USER CODE BEGIN Includes */

#include <stdio.h>
#include <stdlib.h>
#include <string.h>
#include "delay_own.h"
#include "ringbuffer.h"
#include "fnt8x8.h"
#include "6x8_vertikal_LSB_1.h"

//    ______ _ _        _____            _             _ 
//   |  ____| (_)      / ____|          | |           | |
//   | |__  | |_ _ __ | |     ___  _ __ | |_ _ __ ___ | |
//   |  __| | | | '_ \| |    / _ \| '_ \| __| '__/ _ \| |
//   | |    | | | |_) | |___| (_) | | | | |_| | | (_) | |
//   |_|    |_|_| .__/ \_____\___/|_| |_|\__|_|  \___/|_|
//              | |                                      
//              |_|   written by Moritz Kimmig
//                    Version 1.2 (August 2022)
//
//////////////////////////////////////////////////////////
// Changelog:
//
//    V1.0
//      - Initaler Code
//
//    V1.1
//      - Zweite (schmalere) Schriftart implmentiert.
//      - Befehlssatz umgebaut, statt fixer Befehlslänge schließt
//        nun ein Return (0x0A) den jeweiligen Befehl ab
//      - Fehlender PullUp bei SW1-4 aktiviert
//      - "fast_refresh" eingebaut. Wenn dies aktiviert ist, dann
//        wird ein Dot nur noch gesetzt, wenn sich der Zustand vom
//        letzten mal davor geändert hat. Diese Funktion liegt nun
//        auf Schalter SW3.
//      - paar unbenutze Sachen rausgeworfen
//
//    V1.2
//      - Ringpuffer eingebaut und die Befehlsverarbeitung aus dem
//        UART Interrupt entfernt. Desweiteren den Befehlssatz auf
//        lesbare und sinnvolle Befehle umgebaut.
//        Alle Befehle müssen weiterhin mit einem \n abgeschlossen werden.
//      - Textoption für left/center/right, wie auch manuellen Offset eingebaut
//      - Bugfix beim UART Reset
//      - Option für manuelles Refreshen eingefügt (Siehe Schalter 4)
//
//
//    To Do:
//      - Overflow Bug lösen?
//      - erstes/letztes byte von schrift beinhaltet manchmal keine pixel -< beheben!
//


/* USER CODE END Includes */


/* USER CODE BEGIN PV */

//////////////////////////////////////////////////////
// Grundlegende Einstellungen
//////////////////////////////////////////////////////

// BROSE oder LAWO Panel (Änderbar über Onboard Schalter)
// 0 = LAWO
// 1 = BROSE
uint8_t Paneltyp;

// Anzahl Panels (Änderbar über Onboard Schalter)
uint8_t Panelanzahl;





//////////////////////////////////////////////////////
// Variablen
//////////////////////////////////////////////////////

// Pixelspeicher
uint32_t* dots;
uint32_t* dots_old;

// SPI Handler
SPI_HandleTypeDef hspi1;                // SPI_1 (Zeilen ULN2803, UDN2981)
SPI_HandleTypeDef hspi2;                // SPI_2 (Modulauswahl, Daten + Adressleitungen FP2800)
uint8_t hspi2_data[2] = {0x00, 0x00};   // SPI_2 Zwischenspeicher

// UART
uint8_t  uart_puffer = 0;                     // UART Puffer für ein Byte
uint32_t uart_last_time = 0;                  // Zeitmerker, wann letztes Byte kam
#define cmd_buffer_size 100                   // max. Befehlslänge
unsigned char cmd_buffer[cmd_buffer_size];    // Befehlszwischenspeicher

// Text
#define max_text_size 200                     // Puffergröße für Texterzeugung (Pixeldaten)
#define max_cmd_args 10                       // maximale Anzahl an Argumenten pro Befehl
uint8_t textbuffer_8px_UP[max_text_size];     // Zwischenspeicher Pixeldaten
uint8_t textbuffer_8px_DOWN[max_text_size];   // Zwischenspeicher Pixeldaten



// Optionen und Merker
uint8_t enable_fast_refresh = 0;        // Setze nur Dots, welche sich ändern -> schneller! (über Schalter 3 einstellbar!)
uint8_t enable_manually_refresh = 0;    // Nur nach Refresh-Befehl Dots schreiben (Ausnahme: Gelb/Schwarztest) (über Schalter 4 einstellbar!)
uint8_t yellow_test_or_center = 0;
uint8_t yellow_test_or_UP_DOWN = 0;
uint8_t start_refresh = 0;              // Vormerker: Pixeldaten ausgeben
uint8_t start_refresh_center = 0;       // Vormerker: Center Text ausgeben
uint8_t start_refresh_UP = 0;           // Vormerker: Top Text ausgeben
uint8_t start_refresh_DOWN = 0;         // Vormerker: Bottom Text ausgeben
uint8_t start_black = 0;                // Vormerker: Schwarzttest
uint8_t start_yellow = 0;               // Vormerker: Gelbtest


// ENUM für Befehle
enum {
  CMD_ERROR, // error
  CMD_LIGHT,
  CMD_SET_ALL,
  CMD_SET_BUFF,
  CMD_REFRESH,
  CMD_SET_DOT,
  CMD_TEXT_BOTTOM,
  CMD_TEXT_TOP,
  CMD_TEXT_CENTER
};




/* USER CODE END PV */

void SystemClock_Config(void);

/* USER CODE BEGIN PFP */

// Hardware Funktionen
void Zeile_aktivieren(uint8_t Zeile, uint8_t SET_RESET);
void Spalte_aktivieren(uint8_t Spalte, uint8_t SET_RESET);
void Modul_aktivieren(uint8_t Modul, uint8_t ON_OFF);
void Write_Dots(uint8_t from_x, uint8_t to_x, uint8_t from_y, uint8_t to_y);

// Software Funktionen
int generate_text(uint8_t* text_in, uint8_t* text_out, int start, int end, uint8_t text_selector);
uint8_t bit_not_changed(uint8_t x, uint8_t y);
void save_written_dots(void);
int Run_CMD(unsigned char* command);
int isBusy();


/* USER CODE END PFP */

/**
  * @brief  The application entry point.
  *
  * @retval None
  */
int main(void)
{
  /* MCU Configuration----------------------------------------------------------*/

  /* Reset of all peripherals, Initializes the Flash interface and the Systick. */
  HAL_Init();

  /* Configure the system clock */
  SystemClock_Config();

  /* Initialize all configured peripherals */
  MX_GPIO_Init();
  MX_SPI1_Init();
  MX_SPI2_Init();
  MX_USART1_UART_Init();
  MX_TIM2_Init();
  /* USER CODE BEGIN 2 */


  //////////////////////////////////////////////////////
  // Basiseinstellungen abfragen
  //////////////////////////////////////////////////////

  // Switch 1
  // ---------
  #define LAWO 0
  #define BROSE 1
  if(!HAL_GPIO_ReadPin(SW_4_GPIO_Port, SW_4_Pin)) {
    Paneltyp = BROSE; // ON
  } else {
    Paneltyp = LAWO; // OFF
  }

  // Switch 2
  // ---------
  // 0 = 3 Panels (84px  Breite)
  // 1 = 4 Panels (112px Breite)
  if(!HAL_GPIO_ReadPin(SW_3_GPIO_Port, SW_3_Pin)) {
    Panelanzahl = 4; // ON (Brose)
  } else {
    Panelanzahl = 3; // OFF (Lawo)
  }

  // Switch 3
  // ---------
  // 0 = fast_refresh OFF
  // 1 = fast_refresh ON
  if(!HAL_GPIO_ReadPin(SW_2_GPIO_Port, SW_2_Pin)) {
    enable_fast_refresh = 1;
  } else {
    enable_fast_refresh = 0;
  }

  // Switch 4
  // ---------
  // 0 = deaktiviere manuelles Refreshen
  // 1 =   aktiviere manuelles Refreshen
  if(!HAL_GPIO_ReadPin(SW_1_GPIO_Port, SW_1_Pin)) {
    enable_manually_refresh = 1;
  } else {
    enable_manually_refresh = 0;
  }



  //////////////////////////////////////////////////////
  // Speicher initalisieren
  //////////////////////////////////////////////////////

  // Initalzustände aktivieren
  HAL_GPIO_WritePin(Spalten_RESET_GPIO_Port, Spalten_RESET_Pin, 1);
  HAL_GPIO_WritePin(Spalten_OE_GPIO_Port, Spalten_OE_Pin, 0);

  // Pixelspeicher
  dots = (uint32_t*)malloc(Panelanzahl * 28 * sizeof(uint32_t));
  if (dots == NULL) {
    while (1) {

      // Bei Speicherfehler -> blinken
      HAL_GPIO_WritePin(OnboardLED_GPIO_Port, OnboardLED_Pin, 1);
      HAL_Delay(500);
      HAL_GPIO_WritePin(OnboardLED_GPIO_Port, OnboardLED_Pin, 0);
      HAL_Delay(500);
    }
  }

  // Pixelspeicher (letzter Zustand)
  dots_old = (uint32_t*)malloc(Panelanzahl * 28 * sizeof(uint32_t));
  if (dots_old == NULL) {
    while (1) {

      // Bei Speicherfehler -> blinken
      HAL_GPIO_WritePin(OnboardLED_GPIO_Port, OnboardLED_Pin, 1);
      HAL_Delay(500);
      HAL_GPIO_WritePin(OnboardLED_GPIO_Port, OnboardLED_Pin, 0);
      HAL_Delay(500);
    }
  }

  // Pixelspeicher initalisieren
  for (uint8_t i=0; i < Panelanzahl * 28; i++) {
    dots[i] = 0;
    dots_old[i] = 0;
  }

  // Ringbuffer initalisieren
  ringbuffer_init();

  




  //////////////////////////////////////////////////////
  // Interrupts initalisieren
  //////////////////////////////////////////////////////

  // UART1 Interrupt aktivieren
  HAL_UART_Receive_IT(&huart1, &uart_puffer, 1);
  HAL_NVIC_EnableIRQ(USART1_IRQn);

  // Timer2 Interrupt aktivieren (aktuell nicht in Verwendung!!)
  // HAL_TIM_Base_Start_IT(&htim2);



  /* USER CODE END 2 */

  /* Infinite loop */
  /* USER CODE BEGIN WHILE */
  while (1)
  {

  /* USER CODE END WHILE */

  /* USER CODE BEGIN 3 */

  //////////////////////////////////////////////////////
  // Taster u. Variablen Abfragen durchführen
  //////////////////////////////////////////////////////

  // Taster Abfrage: Gelb-Test
  if (!HAL_GPIO_ReadPin(Test_Gelb_GPIO_Port, Test_Gelb_Pin) || start_yellow) {
    uint8_t Zeilen = 0;
    uint8_t enable_fast_refresh_current = enable_fast_refresh;
    enable_fast_refresh = 0; // disable fast_refresh for bl/yl test
    for (uint8_t i=0; i < Panelanzahl * 28; i++)
        dots[i] = 0xFFFFFFFF;
    if (Paneltyp == LAWO)  { Zeilen = 16; }
    if (Paneltyp == BROSE) { Zeilen = 19; }
    Write_Dots(0, (Panelanzahl * 28) - 1, 0, Zeilen - 1);
    enable_fast_refresh = enable_fast_refresh_current;
    yellow_test_or_center = 1;
    yellow_test_or_UP_DOWN = 1;
    start_yellow = 0;

    // Speichere aktuellen Zustand
    save_written_dots();
  }

  // Taster Abfrage: Schwarz-Test
  if (!HAL_GPIO_ReadPin(Test_Schwarz_GPIO_Port, Test_Schwarz_Pin) || start_black) {
    uint8_t Zeilen = 0;
    uint8_t enable_fast_refresh_current = enable_fast_refresh;
    enable_fast_refresh = 0; // disable fast_refresh for bl/yl test
    for (uint8_t i=0; i < Panelanzahl * 28; i++)
        dots[i] = 0x00000000;
    if (Paneltyp == LAWO)  { Zeilen = 16; }
    if (Paneltyp == BROSE) { Zeilen = 19; }
    Write_Dots(0, (Panelanzahl * 28) - 1, 0, Zeilen - 1);
    enable_fast_refresh = enable_fast_refresh_current;
    yellow_test_or_center = 0;
    yellow_test_or_UP_DOWN = 0;
    start_black = 0;

    // Speichere aktuellen Zustand
    save_written_dots();
  }

  // Taster Abfrage: Lampen-Test
  if (!HAL_GPIO_ReadPin(Test_Lampe_GPIO_Port, Test_Lampe_Pin)) {
    static uint32_t blocked_until = 0;
    if (HAL_GetTick() > blocked_until) {
      if (HAL_GPIO_ReadPin(Lampe_GPIO_Port, Lampe_Pin)) {
        HAL_GPIO_WritePin(Lampe_GPIO_Port, Lampe_Pin, 0);
      } else {
        HAL_GPIO_WritePin(Lampe_GPIO_Port, Lampe_Pin, 1);
      }
      blocked_until = HAL_GetTick() + 400;
    }
  }


  //////////////////////////////////////////////////////
  // Anzeigeninhalt aktualisieren
  //////////////////////////////////////////////////////
  if (start_refresh) {
    uint8_t anzahl_spalten = 20;
    if (Paneltyp == LAWO)  { anzahl_spalten=16; }
    if (Paneltyp == BROSE) { anzahl_spalten=19; }
    Write_Dots(0, (Panelanzahl * 28) - 1, 0, anzahl_spalten - 1);
    start_refresh = 0;

    // Speichere aktuellen Zustand
    save_written_dots();
  }




  ////////////////////////////////////////////////////////////
  // Anzeigeninhalt aktualisieren (Text)
  ////////////////////////////////////////////////////////////
  // Text mittig
  if (start_refresh_center) {
    Write_Dots(0, (Panelanzahl * 28) - 1, 4, 11);
    start_refresh_center = 0;

    // Speichere aktuellen Zustand
    save_written_dots();
  }

  // Text oben
  if (start_refresh_UP) {
    uint8_t offset = 0;
    if (Paneltyp == LAWO)  { offset=0; }
    if (Paneltyp == BROSE) { offset=0; }
    Write_Dots(0, (Panelanzahl * 28) - 1, 0, 7+offset);
    start_refresh_UP = 0;

    // Speichere aktuellen Zustand
    save_written_dots();
  }

  // Text unten
  if (start_refresh_DOWN) {
    uint8_t anzahl_spalten = 20;
    if (Paneltyp == LAWO)  { anzahl_spalten=16; }
    if (Paneltyp == BROSE) { anzahl_spalten=19; }
    Write_Dots(0, (Panelanzahl * 28) - 1, anzahl_spalten - 8, anzahl_spalten - 1);
    start_refresh_DOWN = 0;

    // Speichere aktuellen Zustand
    save_written_dots();
  }


  //////////////////////////////////////////////////////
  // UART Buffer auslesen und Befehle starten
  //////////////////////////////////////////////////////
  unsigned char _temp_char = ringbuffer_get();
  static uint32_t cmd_buffer_pos = 0;
  while (_temp_char) {

    // Aktuelles Zeichen in Befehlspuffer laden
    cmd_buffer[cmd_buffer_pos] = _temp_char;
    cmd_buffer_pos++;
    if (cmd_buffer_pos >= cmd_buffer_size) {
      cmd_buffer_pos = 0;
      break;
    }

    // Befehl vollständig ausgelesen ?
    if (_temp_char == '\n') {
      cmd_buffer[cmd_buffer_pos] = '\0';
      cmd_buffer_pos = 0;

      // Befehl ausführen
      Run_CMD(cmd_buffer);
      break;
    }

    // Neues Zeichen aus UART/Ringpuffer laden
    _temp_char = ringbuffer_get();
  }


  //////////////////////////////////////////////////////
  // UART nach 250ms zurücksetzen
  //////////////////////////////////////////////////////
  if (HAL_GetTick() > (uart_last_time + 250) && uart_last_time != 0 && !isBusy()) {
    cmd_buffer_pos = 0;
    ringbuffer_init();
    uart_last_time = HAL_GetTick();
  }
  if (HAL_GetTick() > (uart_last_time + 50)) {
    HAL_GPIO_WritePin(LED_RX_GPIO_Port, LED_RX_Pin,  0);
    uart_last_time = HAL_GetTick();
  }



  }
  /* USER CODE END 3 */

}

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
/* USER CODE BEGIN 4 */

//////////////////////////////////////////////////////
// FlipDot Schreibprozess aktiv?
//////////////////////////////////////////////////////
int isBusy() {
  return start_refresh | start_refresh_center | start_refresh_DOWN | start_refresh_UP | start_yellow | start_black;
}


//////////////////////////////////////////////////////
// UART Interrupts verarbeiten
//////////////////////////////////////////////////////
void HAL_UART_RxCpltCallback(UART_HandleTypeDef *huart) {

  // UART 1
  if (huart->Instance == USART1) {

    // RX LED einschalten
    HAL_GPIO_WritePin(LED_RX_GPIO_Port, LED_RX_Pin,  1);

    //////////////////////////////////////////////////////
    // Daten wegschreiben
    //////////////////////////////////////////////////////
    ringbuffer_pushback((unsigned char)uart_puffer);

    // RX LED wieder ausschalten
    // HAL_GPIO_WritePin(LED_RX_GPIO_Port, LED_RX_Pin,  0);
    // Wird im Hauptprogramm nach einem gewissen Delay wieder ausgeschaltet!

    // Aktuelle Zeit speichern
    uart_last_time = HAL_GetTick();
    
    // Interrupt erneut starten
    HAL_UART_Receive_IT(&huart1, &uart_puffer, 1);
  }
}



//////////////////////////////////////////////////////
// Timer Interrupts verarbeiten
//////////////////////////////////////////////////////
void HAL_TIM_PeriodElapsedCallback(TIM_HandleTypeDef *htim) {

  // Timer 2 (Multiplexing)
  if (htim->Instance == TIM2) {

    // TIMER 2 ist deaktiviert!!

    // Auf nächsten Schritt umschalten und berechnete Zeit warten!
    //__HAL_TIM_SET_COUNTER(&htim2, 0);
    //__HAL_TIM_SET_AUTORELOAD(&htim2, (on_time)+4);
  }
}
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

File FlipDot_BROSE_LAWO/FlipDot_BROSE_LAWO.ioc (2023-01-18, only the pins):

Mcu.UserName=STM32F103C8Tx
PA1.GPIO_Label=RS485_EN
PA1.Signal=GPIO_Output
PA10.Signal=USART1_RX
PA13.Signal=SYS_JTMS-SWDIO
PA14.Signal=SYS_JTCK-SWCLK
PA2.GPIO_Label=Lampe
PA2.Signal=GPIO_Output
PA3.GPIO_Label=Zeilen_SET_RESET
PA3.Signal=GPIO_Output
PA4.GPIO_Label=Zeilen_OE
PA4.Signal=GPIO_Output
PA5.GPIO_Label=Zeilen_CLK
PA5.Signal=SPI1_SCK
PA6.GPIO_Label=Zeilen_LATCH
PA6.Signal=GPIO_Output
PA7.GPIO_Label=Zeilen_D
PA7.Signal=SPI1_MOSI
PA8.GPIO_Label=Spalten_RESET
PA8.Signal=GPIO_Output
PA9.Signal=USART1_TX
PB0.GPIO_Label=Test_Lampe
PB0.Signal=GPIO_Input
PB1.GPIO_Label=Test_Schwarz
PB1.Signal=GPIO_Input
PB10.GPIO_Label=Test_Gelb
PB10.Signal=GPIO_Input
PB11.GPIO_Label=Reset
PB11.Signal=GPIO_Output
PB12.GPIO_Label=Spalten_OE
PB12.Signal=GPIO_Output
PB13.GPIO_Label=Spalten_CLK
PB13.Signal=SPI2_SCK
PB14.GPIO_Label=Spalten_LATCH
PB14.Signal=GPIO_Output
PB15.GPIO_Label=Spalten_D
PB15.Signal=SPI2_MOSI
PB3.GPIO_Label=SW_4
PB3.Signal=GPIO_Input
PB4.GPIO_Label=SW_3
PB4.Signal=GPIO_Input
PB5.GPIO_Label=SW_2
PB5.Signal=GPIO_Input
PB6.GPIO_Label=SW_1
PB6.Signal=GPIO_Input
PB7.GPIO_Label=LED_RX
PB7.Signal=GPIO_Output
PB8.GPIO_Label=LED_Status
PB8.Signal=GPIO_Output
PC13-TAMPER-RTC.GPIO_Label=OnboardLED
PC13-TAMPER-RTC.Signal=GPIO_Output
PC14-OSC32_IN.Signal=RCC_OSC32_IN
PC15-OSC32_OUT.Signal=RCC_OSC32_OUT
PD0-OSC_IN.Signal=RCC_OSC_IN
PD1-OSC_OUT.Signal=RCC_OSC_OUT

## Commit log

2023-01-18 added all files
    [untitled.brd, untitled.sch]
2023-03-30 fixed pcb mistake

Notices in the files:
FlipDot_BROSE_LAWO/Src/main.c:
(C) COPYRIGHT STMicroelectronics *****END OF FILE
